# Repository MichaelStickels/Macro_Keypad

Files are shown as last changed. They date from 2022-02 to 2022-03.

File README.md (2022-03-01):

# Macro_Keypad

Low-cost Arduino-based fully customizable 8 key macro keypad with relegendable keycaps. 

<div align="center">
  <kbd>
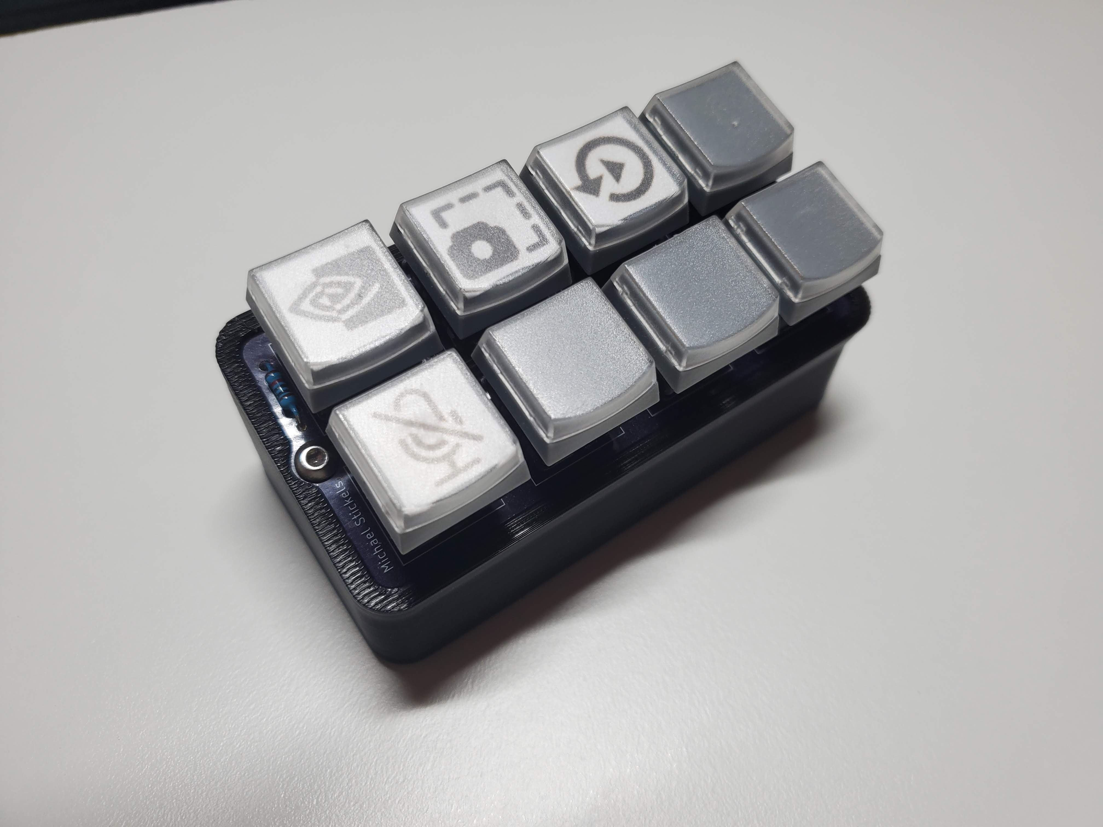
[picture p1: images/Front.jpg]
    
  </kbd>
</div>

## Description

This small 4x2 macro keypad offers 8 fully customizeable keys at easy reach for productivity, creative work, gaming, or other use cases. Set each key to any combination of button presses and add your own icons to the relegendable keycaps to have any shortcut, macro, or keybind ready at the push of a button. The custom PCB provides a rigid deck for the keys, as well as n-key rollover and LED backlighting. The 3D printed case angles the keys towards you for ease of use and rubber feet for grip on a slick desk.

### Features

- Low-cost, especially compared to similar products on the market ([Elgato Stream Deck](https://www.elgato.com/en/stream-deck)).
- Easily customizeable: Design your own icons for the keycaps and set each key to any combination of button presses you want in the Arduino file.
- LED backlight ready.
- Open source and fully customizeable.

### Parts

- Arduino Pro Micro (or knockoff) [[link](https://www.sparkfun.com/products/12640)]
- Cherry MX Switches [[link](https://www.digikey.com/en/products/detail/cherry-americas-llc/MX1A-11NW/91134)]
- Relegendable Keycaps [[link](https://www.amazon.com/dp/B01M023NFK?psc=1)]
- Some Headers and Jumper Cables/Wires
- 10kΩ Pullup Resistors
- 1N4148 Diodes (or similar)

I used some heat-set threaded inserts, but if you wanted to cut cost you could just screw directly into the plastic case or even just use some hot glue to secure the PCB.

### Disclaimer

Most of my projects are ongoing or work-in-progress. They are not intended to be finalized production-ready products, and should not be treated as such. Feel free to use any of the materials in this project to make your own or adapt to your own project, within the guidelines of the license.

## Getting started

### Prerequisites

Any Arduino can be used, as long as it is capable of acting as a HID (Human Interface Device). To find out if your Arduino supports it, simply google '[Arduino Name] HID keyboard'.

**Note:** The case design may need modifying to fit a different or larger board.
<!--
### Install

Ideally, write a script whose usage is described here.

### Configure

Manual, context-specific tasks not covered in the installation process.

### Usage

GIFs are useful here to see the project in action.

### Troubleshooting

Or FAQs, if that's more appropriate.
-->
## Photos

Some more photos of the project and the build process.

<div align="center">
  <kbd>
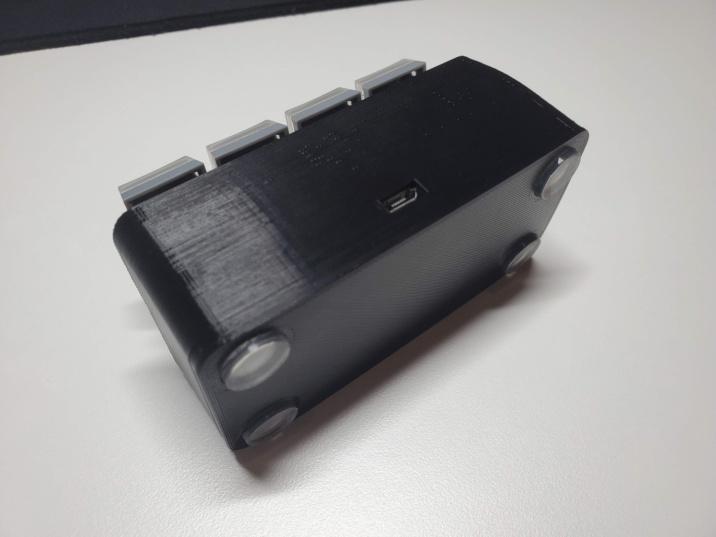
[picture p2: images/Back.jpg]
    
  </kbd>
    
  Micro USB connection on the back (from Arduino Pro Micro) and some rubber feet to prevent sliding.
</div>

<div align="center">
  <kbd>
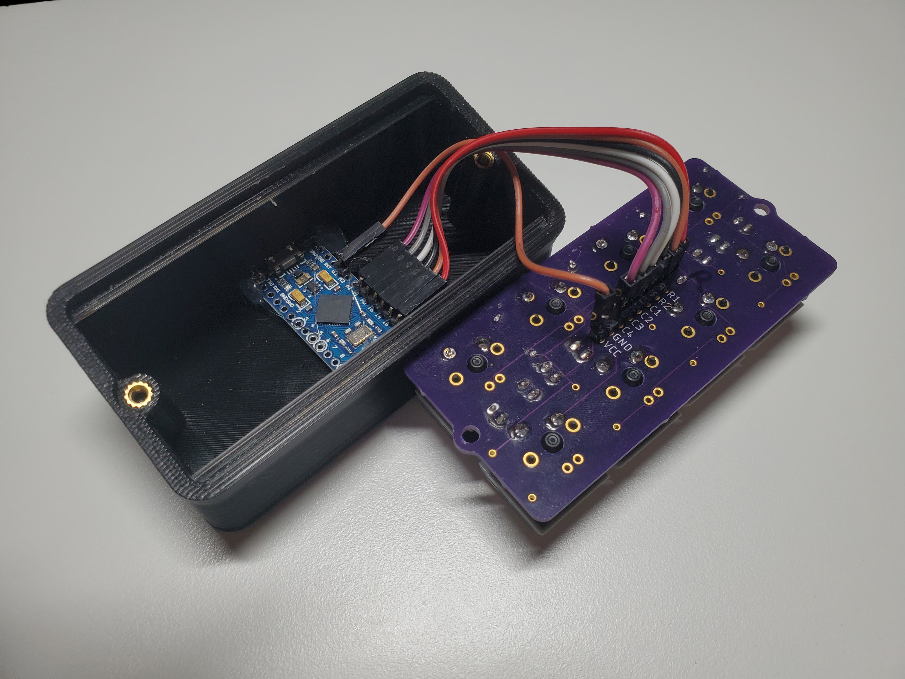
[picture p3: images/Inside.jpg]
    
  </kbd>
    
  Arduino hot-glued into the case and short jumper cables for PCB connections. I chose to use threaded heat-set inserts for the mount, but you could just as easily screw directly into the plastic.
</div>

<div align="center">
  <kbd>
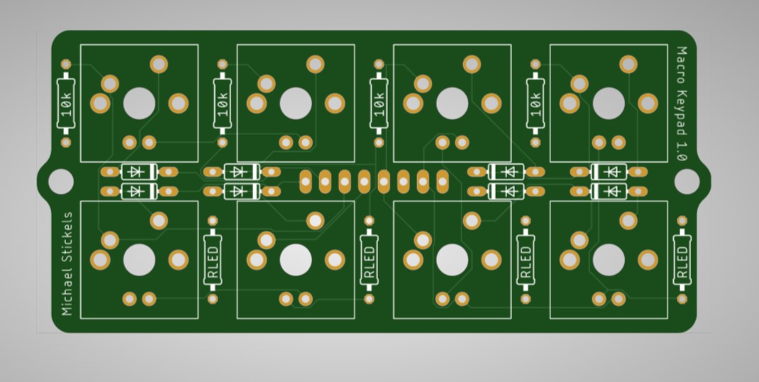
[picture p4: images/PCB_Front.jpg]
    
  </kbd>
    
  Custom PCB layout and labels.
</div>

<!--
### Legal disclaimer

Usage of this tool for attacking targets without prior mutual consent is illegal. It is the end user's responsibility to obey all applicable local, state, and federal laws. Developers assume no liability and are not responsible for any misuse or damage caused by this program.
-->
<!--
### See also

- [A simple README.md template](https://gist.github.com/DomPizzie/7a5ff55ffa9081f2de27c315f5018afc)
- [A template to make good README.md](https://gist.github.com/PurpleBooth/109311bb0361f32d87a2)
- [A sample README for all your GitHub projects](https://gist.github.com/fvcproductions/1bfc2d4aecb01a834b46)
- [A simple README.md template to kickstart projects](https://github.com/me-and-company/readme-template)

## To-do

- [ ] Still need to do this
- [ ] ~~Decided not to do this~~
- [x] Done!
-->

## License

This project is licensed under the [GPL-3.0 License](LICENSE).

## Acknowledgments

* [Project inspiration from Parts Not Included](https://www.partsnotincluded.com/diy-stream-deck-mini-macro-keyboard/)
* [Keypad_Matrix Library by nickgammon](https://github.com/nickgammon/Keypad_Matrix)

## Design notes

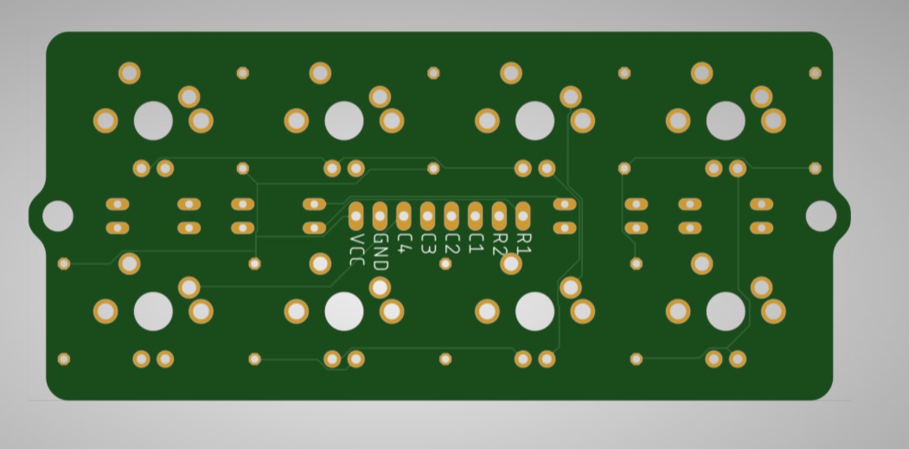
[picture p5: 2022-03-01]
images/PCB_Back.jpg

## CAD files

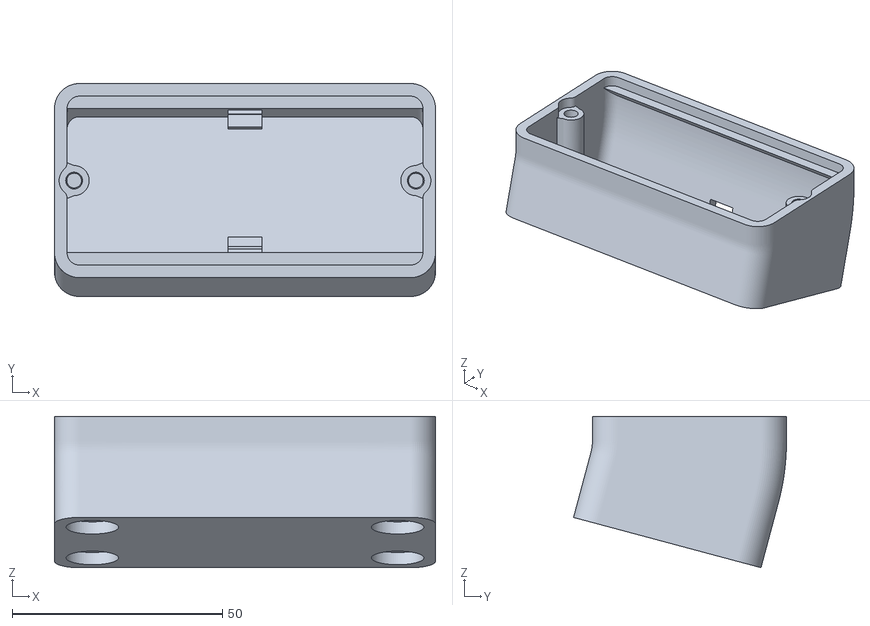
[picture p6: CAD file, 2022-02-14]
Case/Case REV02.stl
90.6 x 50.7 x 36.0

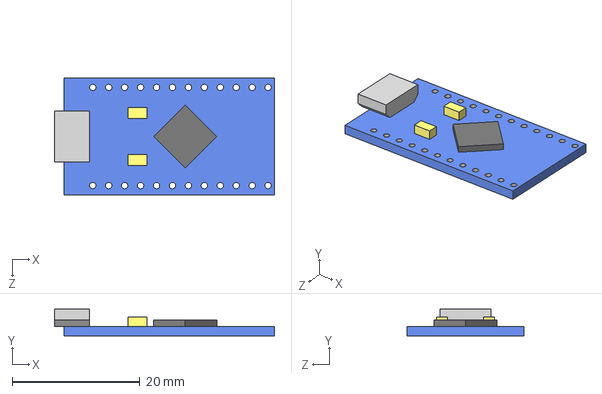
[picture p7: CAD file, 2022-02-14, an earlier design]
Old Revisions/Arduino/Arduino Pro Micro.STEP
34.5 x 4.20 x 18.4 mm

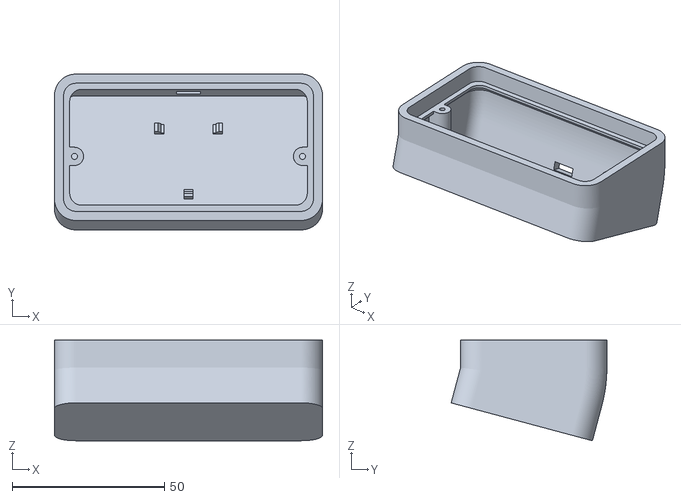
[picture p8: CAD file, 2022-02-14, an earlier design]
Old Revisions/Case REV02.stl
88.1 x 51.2 x 33.0

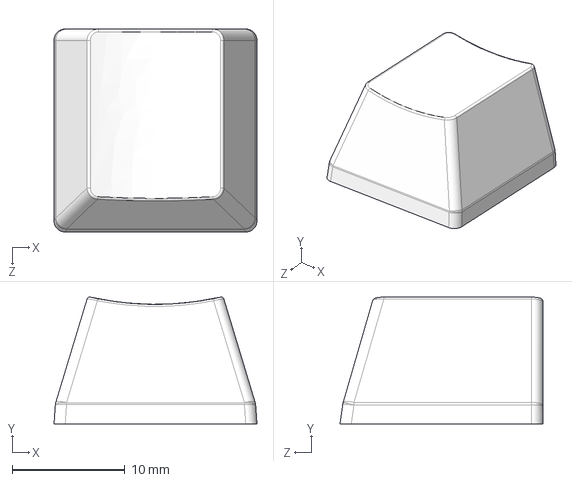
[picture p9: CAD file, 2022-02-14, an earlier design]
Old Revisions/Keycap/MX 轴标准键帽.STEP
18.0 x 11.3 x 18.0 mm

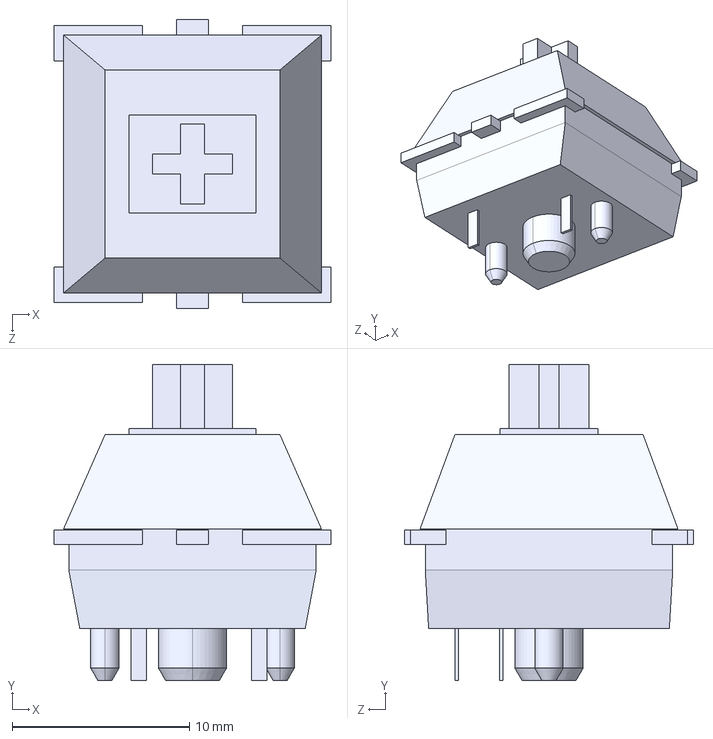
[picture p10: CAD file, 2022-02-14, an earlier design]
Old Revisions/Switch/cherry mx.STEP
15.6 x 17.9 x 16.3 mm

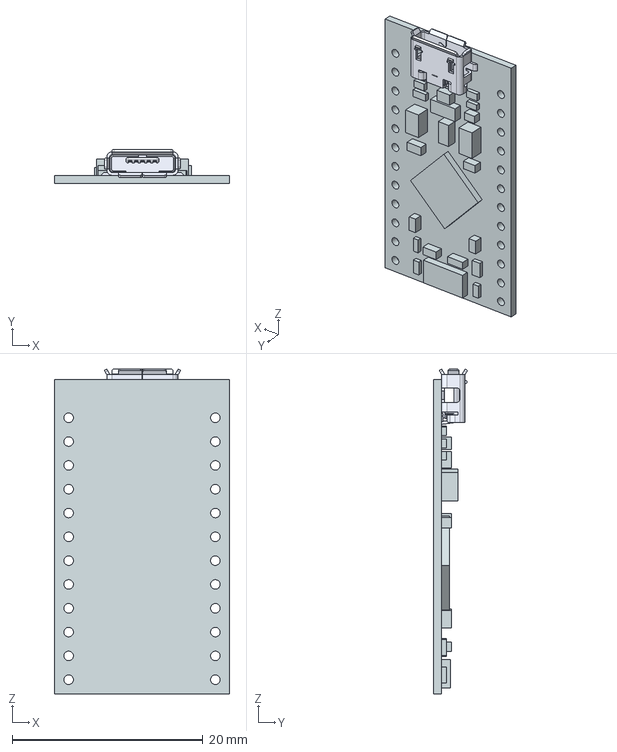
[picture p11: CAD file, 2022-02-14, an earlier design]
Old Revisions/Arduino/Arduino Pro Micro Sparkfun.stp
18.4 x 3.58 x 34.1 mm

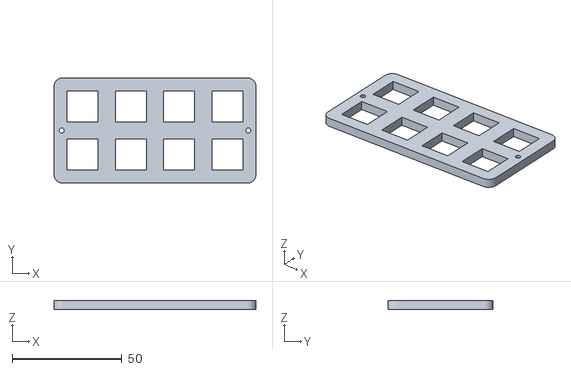
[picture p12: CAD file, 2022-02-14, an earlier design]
Old Revisions/Plate REV02.stl
92.0 x 48.0 x 4.00

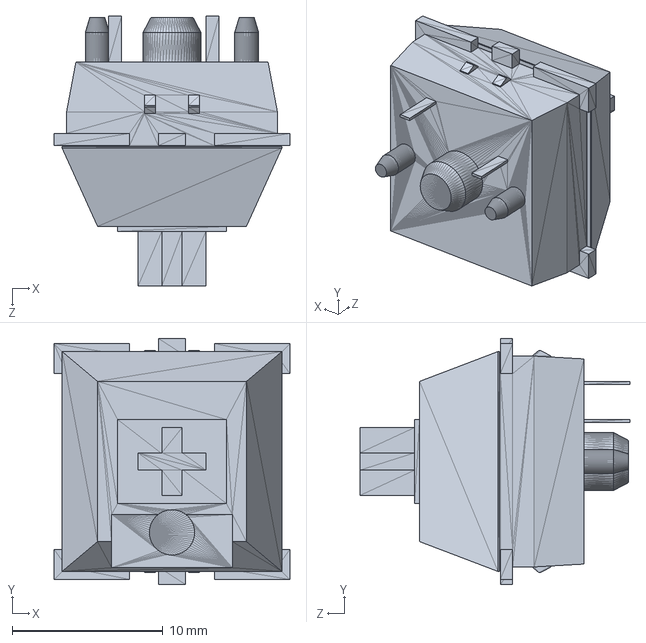
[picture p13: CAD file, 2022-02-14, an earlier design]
Old Revisions/Switch/cherry old.SLDPRT
15.6 x 16.3 x 17.9 mm

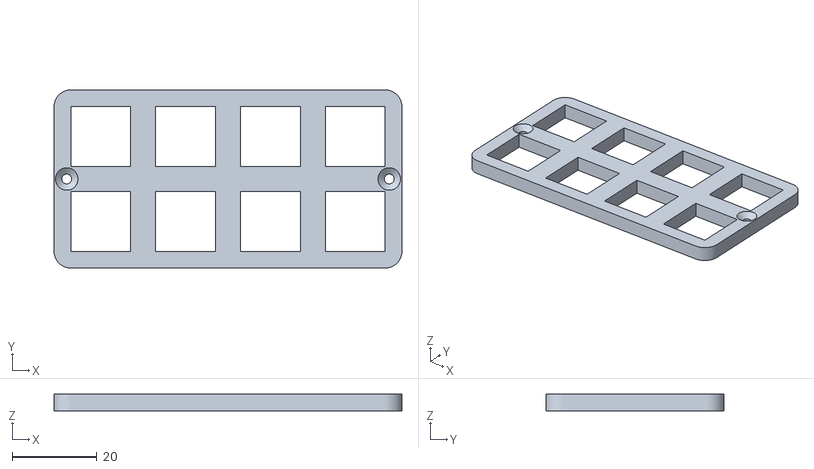
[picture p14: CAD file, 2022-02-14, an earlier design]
Old Revisions/Plate REV03.stl
82.0 x 42.0 x 4.00

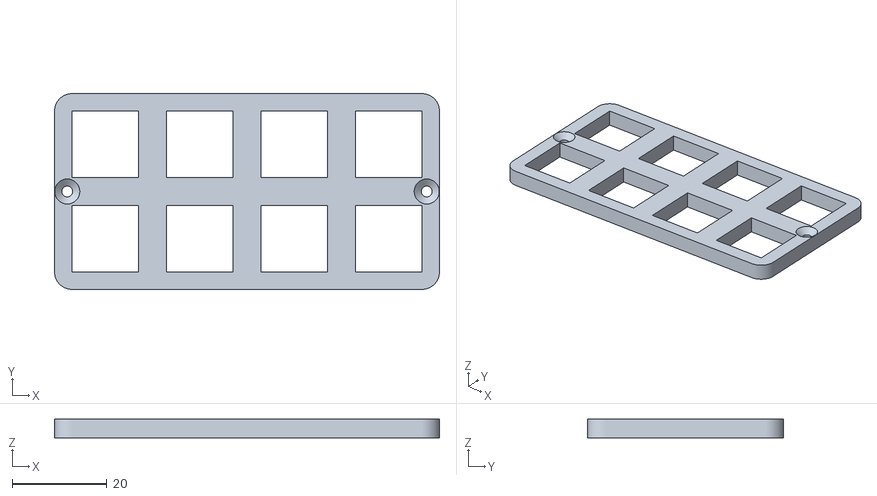
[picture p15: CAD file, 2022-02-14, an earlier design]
Old Revisions/Plate REV04.stl
81.4 x 41.4 x 4.00

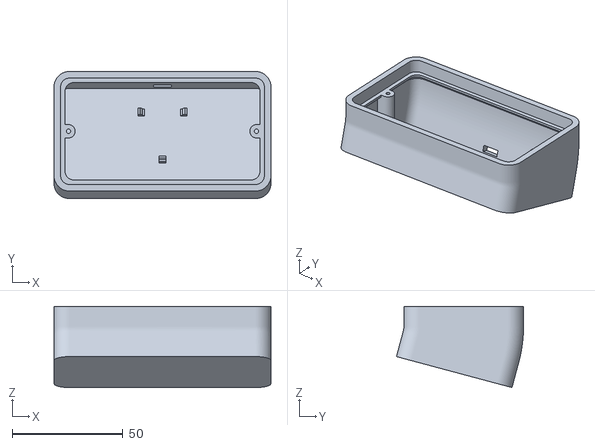
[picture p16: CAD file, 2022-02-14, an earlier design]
Old Revisions/Case.stl
98.1 x 57.5 x 36.7

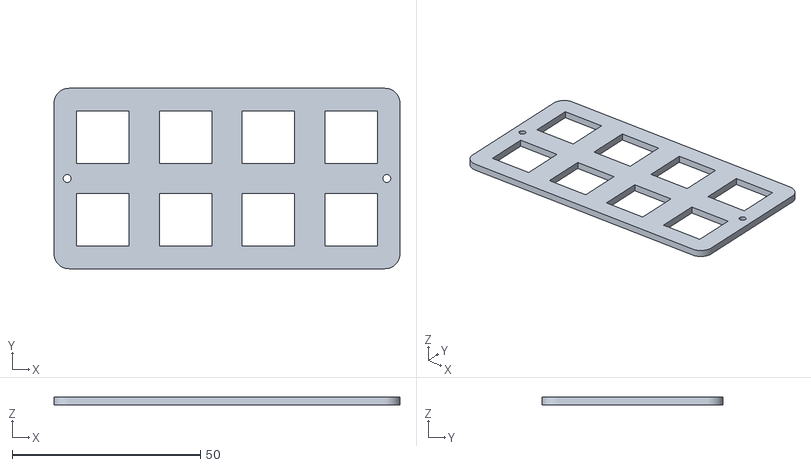
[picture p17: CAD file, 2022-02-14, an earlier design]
Old Revisions/Plate.stl
92.0 x 48.0 x 2.10

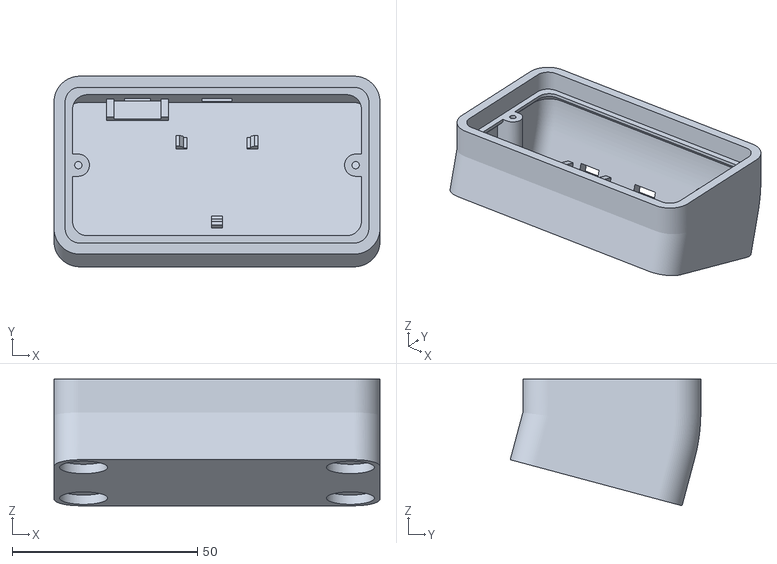
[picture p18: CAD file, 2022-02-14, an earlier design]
Old Revisions/Case REV04.stl
88.1 x 51.5 x 34.2

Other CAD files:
Case/Case REV01.stl
Old Revisions/Case REV03.stl
Case/Case.ipt
Old Revisions/Arduino/Arduino Pro Micro Sparkfun.igs
Old Revisions/Arduino/Arduino Pro Micro Sparkfun.ipt
Old Revisions/Arduino/Arduino Pro Micro Sparkfun.prt
Old Revisions/Arduino/Arduino Pro Micro.x_b
Old Revisions/Arduino/MICRO_USB_SMD_CONNECTOR.prt
Old Revisions/Arduino/PCB Pro Micro.prt
Old Revisions/Case.ipt
Old Revisions/Keycap/MX 轴标准键帽.SLDPRT
Old Revisions/Keycap/MX 轴标准键帽.STL
Old Revisions/Keycap/MX 轴标准键帽.ipt
Old Revisions/M2 Screw.ipt
Old Revisions/Old/Assembly.iam
Old Revisions/Old/Base Wide.ipt
Old Revisions/Old/Base.ipt
Old Revisions/Old/Key Cap Hole Test.ipt
Old Revisions/Old/Key Plate Wide.ipt
Old Revisions/Old/Key Plate.ipt
Old Revisions/Old/Print Assembly.iam
Old Revisions/Old/Wide Assembly.iam
Old Revisions/OldVersions/Assembly.0005.iam
Old Revisions/OldVersions/Base Wide.0002.ipt
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

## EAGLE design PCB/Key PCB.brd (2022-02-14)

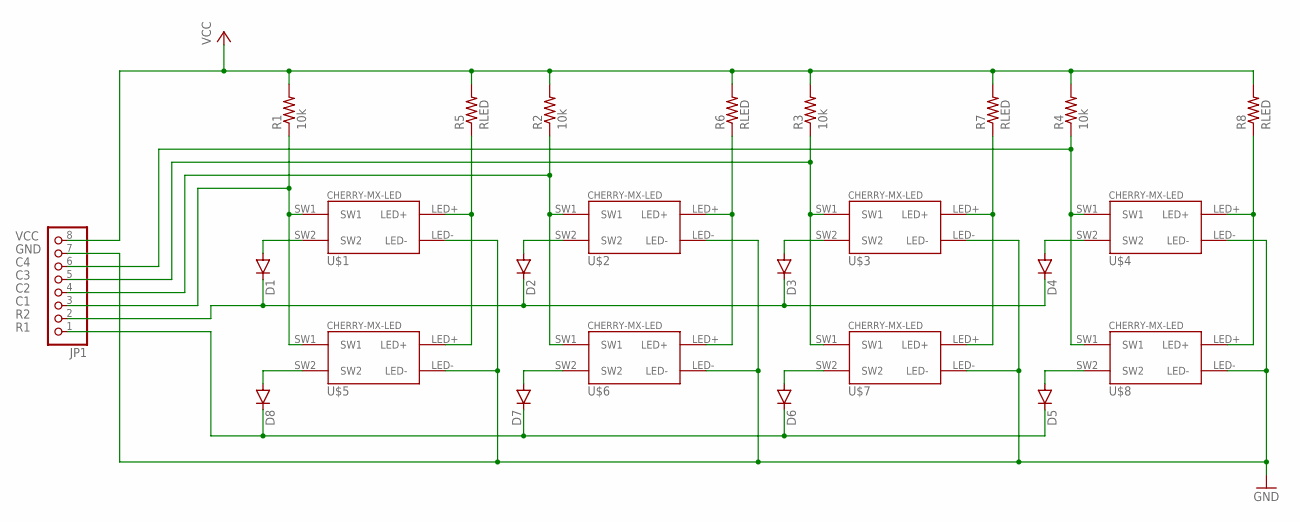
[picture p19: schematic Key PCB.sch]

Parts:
D1, D2, D3, D4, D5, D6, D7, D8: 1N4148DO35-7; DO35-7
JP1: PINHD-1X8; 1X08
R1, R2, R3, R4: 10k; 0207/10
R5, R6, R7, R8: RLED; 0207/10
U$1, U$2, U$3, U$4, U$5, U$6, U$7, U$8: CHERRY-MX-LED

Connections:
C1: JP1.3, R1.1, U$1.SW1, U$5.SW1
C2: JP1.4, R2.1, U$2.SW1, U$6.SW1
C3: JP1.5, R3.1, U$3.SW1, U$7.SW1
C4: JP1.6, R4.1, U$4.SW1, U$8.SW1
GND: JP1.7, U$1.LED-, U$2.LED-, U$3.LED-, U$4.LED-, U$5.LED-, U$6.LED-, U$7.LED-, U$8.LED-
unnamed: D4.A, U$4.SW2
unnamed: D1.A, U$1.SW2
unnamed: D2.A, U$2.SW2
unnamed: D3.A, U$3.SW2
unnamed: D6.A, U$7.SW2
unnamed: D7.A, U$6.SW2
unnamed: D8.A, U$5.SW2
unnamed: D5.A, U$8.SW2
unnamed: R5.1, U$1.LED+, U$5.LED+
unnamed: R6.1, U$2.LED+, U$6.LED+
unnamed: R7.1, U$3.LED+, U$7.LED+
unnamed: R8.1, U$4.LED+, U$8.LED+
R1: D5.C, D6.C, D7.C, D8.C, JP1.1
R2: D1.C, D2.C, D3.C, D4.C, JP1.2
VCC: JP1.8, R1.2, R2.2, R3.2, R4.2, R5.2, R6.2, R7.2, R8.2

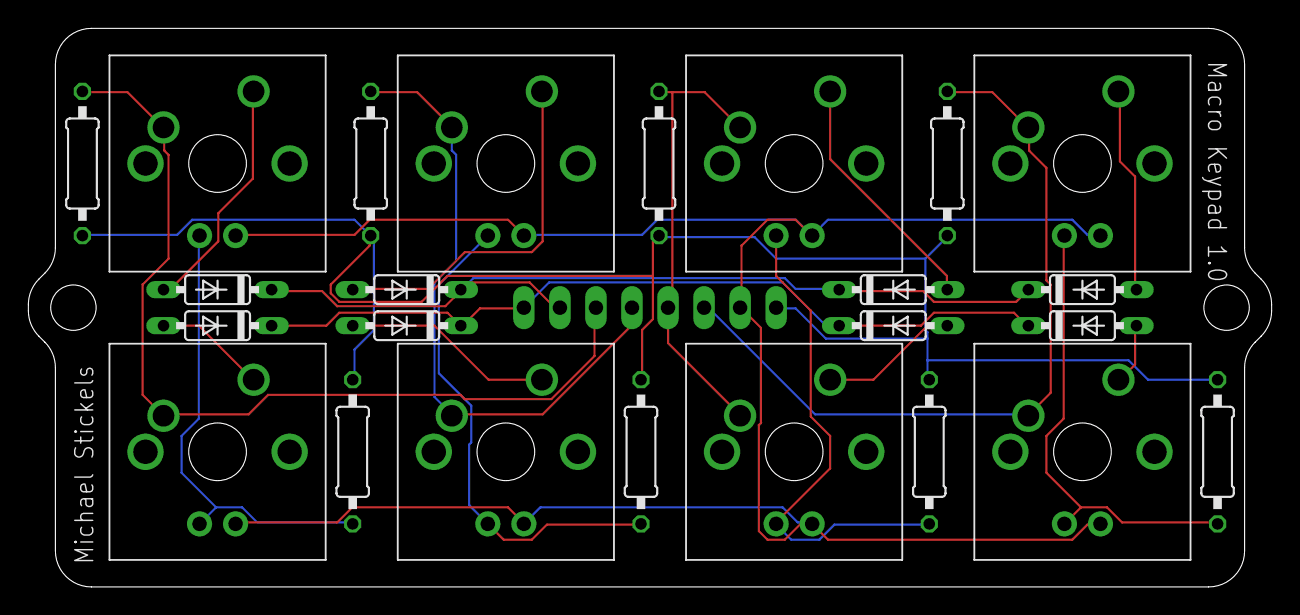
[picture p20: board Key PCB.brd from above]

Board: 2 copper layers, 87.6 x 39.4 mm, 25 parts (0 on the bottom side), 20 nets.

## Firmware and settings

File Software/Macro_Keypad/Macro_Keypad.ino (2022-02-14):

/*

  Macro_Keypad Firmware

  Michael Stickels
  
  Last Updated: 02/14/2022

  GPL-3.0 License

*/

// Import Libraries
#include <Keypad_Matrix.h>
#include <Keyboard.h>

// Define keypress for keys 1-8
#define KEY1 KEY_F13
#define KEY2 KEY_F14
#define KEY3 KEY_F15
#define KEY4 KEY_F16
#define KEY5 KEY_F8
#define KEY6 KEY_F18
#define KEY7 KEY_F9
#define KEY8 KEY_F20
#define ALT KEY_LEFT_ALT

// Define keypad size and layout
const byte ROWS = 2;
const byte COLS = 4;
const char keys[ROWS][COLS] = {{'1','2','3','4'},{'5','6','7','8'}};

// Define Arduino pins
const byte rowPins[ROWS] = {10, 16};
const byte colPins[COLS] = {14, 15, 18, 19};

// Initialize keypad object
Keypad_Matrix kpd = Keypad_Matrix(makeKeymap (keys), rowPins, colPins, ROWS, COLS);


/*

  To set custom macros, edit the case for the desired button in *BOTH* keyDown and keyUp.
  Ensure that each Keyboard.press() is accompanied by a Keyboard.release() statement, or
  the key will get "stuck down". Any reasonable combination of keys can be set, including
  modifiers and multiple keypresses.

  See https://www.arduino.cc/en/Reference/KeyboardModifiers for modifier keys 

*/


// Handler for keyDown event (key pressed down)
void keyDown (const char which)
  {
  switch (which) {

  // Key 1 press
  case '1':
    Keyboard.press(KEY1);
    break;

  // Key 2 press
  case '2':
    Keyboard.press(KEY2);
    break;

  // Key 3 press
  case '3':
    Keyboard.press(KEY3);
    break;

  // Key 4 press
  case '4':
    Keyboard.press(KEY4);
    break;

  // Key 5 press
  case '5':
    Keyboard.press(ALT);
    Keyboard.press(KEY5);
    break;

   case '6':
   // Key 6 press
    Keyboard.press(KEY_LEFT_CTRL);
    Keyboard.press(KEY_LEFT_ALT);
    Keyboard.press(206); // print screen
    break;

  case '7':
  // Key 7 press
    Keyboard.press(KEY_LEFT_ALT);
    Keyboard.press(KEY7);
    break;

  // Key 8 press
  case '8':
    Keyboard.press(KEY8);
    break;
}
  }

// Handler for keyUp event (key unpressed)
void keyUp (const char which)
  {
  switch (which) {

  // Key 1 release
  case '1':
    Keyboard.release(KEY1);
    break;

  // Key 2 release
  case '2':
    Keyboard.release(KEY6);
    break;

  // Key 3 release
  case '3':
    Keyboard.release(KEY3);
    break;

  // Key 4 release
  case '4':
    Keyboard.release(KEY4);
    break;

  // Key 5 release
  case '5':
    Keyboard.release(ALT);
    Keyboard.release(KEY5);
    break;

  // Key 6 release
  case '6':
    Keyboard.release(KEY_LEFT_CTRL);
    Keyboard.release(KEY_LEFT_ALT);
    Keyboard.release(206);
    break;

  // Key 7 release
  case '7':
    Keyboard.release(KEY_LEFT_ALT);
    Keyboard.release(KEY7);
    break;
    
  // Key 8 release
  case '8':
    Keyboard.release(KEY8);
    break;
  }
}


// 
void setup() {
  // small delay for interrupting setup via write if needed
  delay(1000);
  kpd.begin ();
  kpd.setKeyDownHandler (keyDown);
  kpd.setKeyUpHandler   (keyUp);
  Keyboard.begin();
}

void loop() {
  kpd.scan ();
}
